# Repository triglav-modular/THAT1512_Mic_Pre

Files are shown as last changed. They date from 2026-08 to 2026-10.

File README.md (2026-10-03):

# µAmp
A THAT1512 microphone preamp. This is a very simple board with a THAT1512 based preamp for replacing the one in the Buchla 208 for a much lower noise floor and higher gain. Wire between the preamp jack and T.P.1 on card 10. Lower R6 on card 10 to compensate for the gain increase.

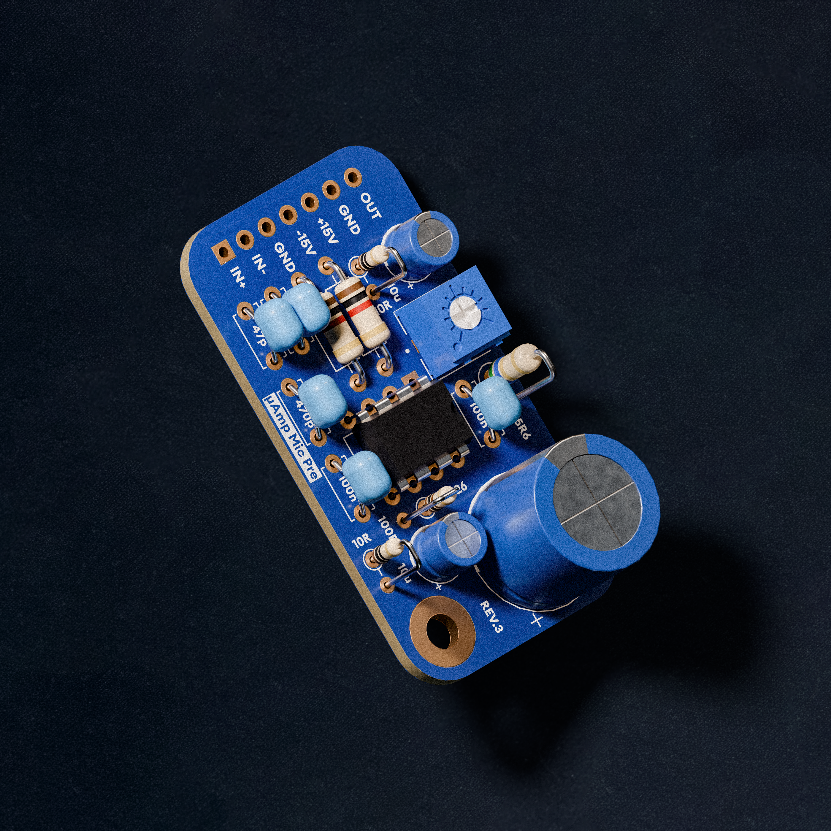
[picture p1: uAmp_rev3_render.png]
3D render of the assembled rev3 THAT1512 mic preamp board


The board is 45 × 24 mm with a single M3 mounting hole. Gain is set by the 1K trimmer (RV1, a Bourns 3362P): about 15 dB at full resistance up to about 59 dB at zero, where the 5.6 Ω R6 sets the top of the range.

## Header pinout

Pin 1 is the square pad.

| Pin | 1 | 2 | 3 | 4 | 5 | 6 | 7 |
|---|---|---|---|---|---|---|---|
| | i+ | i− | g | −v | +v | g | out |

## Revisions

**rev3 (2026)** — same outline, header pinout and mounting hole as rev2, so it is a drop-in replacement.

- Corrected part numbers: U1 is THAT1512P08-U (was 1510), C4/C5 are 100 nF (were 470 pF part numbers), R1/R2 are 1 kΩ (were 6.81 kΩ part numbers), RV1 is 1 kΩ.
- R3 100 Ω in series with the output, to isolate the THAT1512 from the capacitance of the wire to card 10 (it is specified for 300 pF at most).
- R6 5.6 Ω in series with RV1, so maximum gain is set by a resistor rather than by the trimmer's end resistance.
- R4/C7 and R5/C8: 10 Ω and 10 µF on each supply rail.
- No output coupling capacitor is needed: card 10 AC-couples after T.P.1, and C6 holds the output offset to a few mV.

**rev2 (2022)** — the board fitted in the 208, tagged `rev2`. Its raytraced render is `uAmp_3D_render.png`.

## Bill of materials (rev3)

| Ref | Value | Part number | Notes |
|---|---|---|---|
| U1 | THAT1512 | THAT1512P08-U | DIP-8 |
| RV1 | 1 kΩ trimmer | Bourns 3362P-1-102LF | |
| C1, C2 | 470 pF | Murata RDE5C2A471J0M1H03A | C0G, 5 mm pitch |
| C3 | 47 pF | Murata RDE5C2A470J0M1H03A | C0G, 5 mm pitch |
| C4, C5 | 100 nF | Murata RDER71H104K0M1H03A | X7R, 5 mm pitch |
| C6 | 6800 µF 6.3 V | Nichicon UVZ0J682MHD | 12.5 × 25 mm, 5 mm pitch. Polarized is correct here: both gain pins sit at the same DC level. Bipolar 6800 µF only comes as 18 × 35.5 mm, which does not fit |
| C7, C8 | 10 µF 50 V | Panasonic EEU-FR1H100 | 5 mm diameter, 2 mm pitch |
| R1, R2 | 1 kΩ 0.1 % | Vishay CMF551K0000BEEK | |
| R3 | 100 Ω | Vishay MBA02040C1000FC100 | mounted vertically |
| R4, R5 | 10 Ω | Vishay MBA02040C1009FC100 | mounted vertically |
| R6 | 5.6 Ω | Vishay MBB02070C5608FCT00 | mounted vertically |
| J1 | 1×7 pin header | | 2.54 mm |

## Substituting the SSM2019

THAT Corporation put the 1510 and 1512 on end-of-life status on 1 September 2026 ([memo](https://thatcorp.com/wp-content/uploads/2026/09/THAT-EOL-Memo.pdf)). The Analog Devices SSM2019BNZ (DIP-8) has the same pinout and fits U1 with no board change.

Its gain is 1 + 10 kΩ/Rg where the THAT1512's is 0.5 + 5 kΩ/Rg, so with the rev3 values the range moves up about 6 dB, to 21–65 dB. Two value changes bring it back to about 15.5–59 dB:

| Ref | With THAT1512 | With SSM2019 |
|---|---|---|
| R6 | 5.6 Ω | 11 Ω |
| RV1 | 1 kΩ (3362P-1-102LF) | 2 kΩ (3362P-1-202LF) |

Nothing else changes; C6 then rolls off near 2 Hz at full gain instead of 4 Hz.

By the datasheets the SSM2019 matches the THAT1512's 1 nV/√Hz input noise at 60 dB and is a little noisier below 40 dB (7 against 4.6 nV/√Hz at 20 dB). Its bandwidth at 60 dB is 200 kHz against 1.6 MHz, and its distortion there is about twice as high (0.017 % against 0.008 %, measured under different conditions). It drives 5000 pF where the THAT1512 is limited to 300 pF.

The TI INA217 shares the pinout and the SSM2019's gain equation, but TI no longer lists it in DIP-8.

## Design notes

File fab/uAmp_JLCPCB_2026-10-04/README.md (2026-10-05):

# µAmp rev 3 — JLCPCB bare-board package

Generated 2026-10-04 from `uAmp.kicad_pcb` as saved 2026-10-04 10:15:07
(sha256 `34b1dd3746bd…`), KiCad 10.0.6, `kicad-cli`. Bare boards only: no BOM,
no placement file.

Re-exported after the 09:58 package. The only change is that "TRIGLAV MODULAR"
moved on the back silkscreen. Apart from creation dates, only
`uAmp-B_Silkscreen.gbo` differs from the 09:58 files. KiCad also writes an empty
NPTH drill file and its map; both are left out because the board has no
unplated holes.

## Contents

| File | Purpose |
|---|---|
| `uAmp-gerbers.zip` | **upload this**: 9 gerbers, the job file and the drill file |
| `gerbers/` | the same files unzipped, plus the drill map PDF |

## Order parameters

| | |
|---|---|
| Dimensions | 45.00 × 24.03 mm, rounded corners |
| Layers | 2 |
| Thickness | 1.6 mm |
| Material | FR4 |
| Surface finish | HASL or ENIG, no constraint from this design |
| Min track / space | 0.50 / 0.25 mm |
| Vias | none |
| Copper to board edge | 0.20 mm or more |
| Holes | 47, all plated: 6 × 0.7, 3 × 0.714, 28 × 0.8, 7 × 1.0, 2 × 1.2, 1 × 3.2 mm (M3) |
| Order number | no marker on the board (the owner removed it 2026-10-04) |

## Verification performed

- DRC on the saved board: 0 errors, 0 unconnected, 11 warnings (10 library
  differences, 1 missing footprint library for RV1). One schematic-parity
  warning: U1's Value field.
- The saved zone fill equals a fresh fill (the owner refilled and saved;
  1210 mm² of GND pour over both layers).
- The project's copper-to-edge rule is 0.075 mm. DRC on a copy with the rule
  raised to 0.20 mm (JLCPCB's routed-edge minimum) and the zones refilled
  reports nothing.
- Read back from the files in this folder: the drill file's six tools and 47
  hits equal the board's pad holes; the outline is 45.000 × 24.030 mm; no
  coordinate on any layer lies outside it; the job file and the copper headers
  say 2 layers; the zip holds the same bytes as `gerbers/`.
- Silk gerbers are exported with the mask openings subtracted
  (`--subtract-soldermask`).
- Front and mirrored back plotted with the same options and looked at: the
  "µAmp Mic Pre" knockout plots with its µ; "TRIGLAV MODULAR" on the back reads
  the right way round.

## Not checked

- JLCPCB's own gerber preview. Look at it before paying.
- Silk text is 0.8 to 0.9 mm high; JLCPCB asks for 1.0 mm.

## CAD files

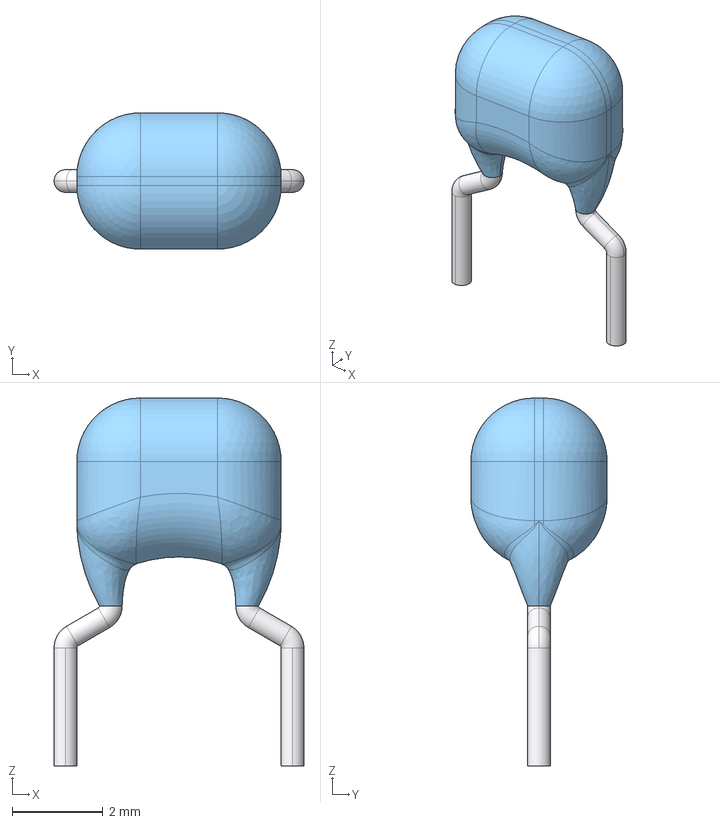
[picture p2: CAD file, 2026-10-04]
3dmodels/C_Ceramic_Dipped_P5.00mm.step
5.50 x 3.00 x 8.10 mm
leads

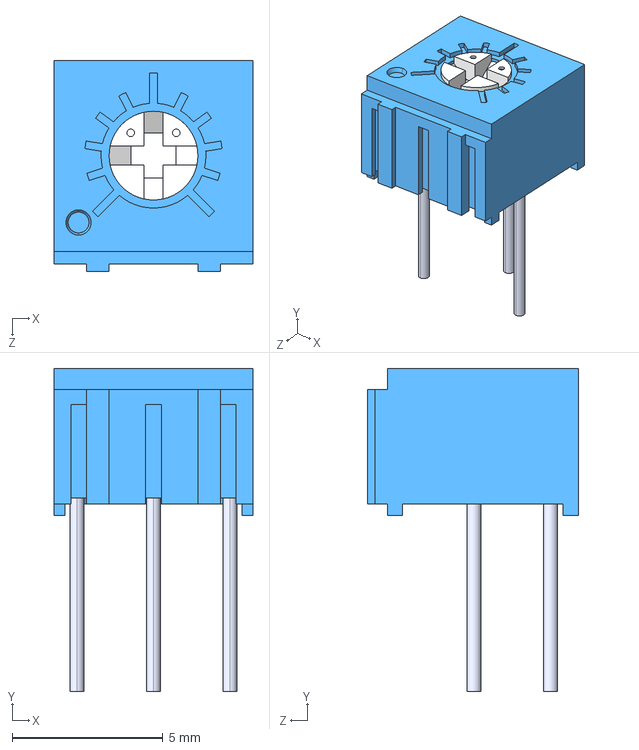
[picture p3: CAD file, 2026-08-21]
3dmodels/3362p-1-103.stp
6.60 x 10.7 x 6.99 mm

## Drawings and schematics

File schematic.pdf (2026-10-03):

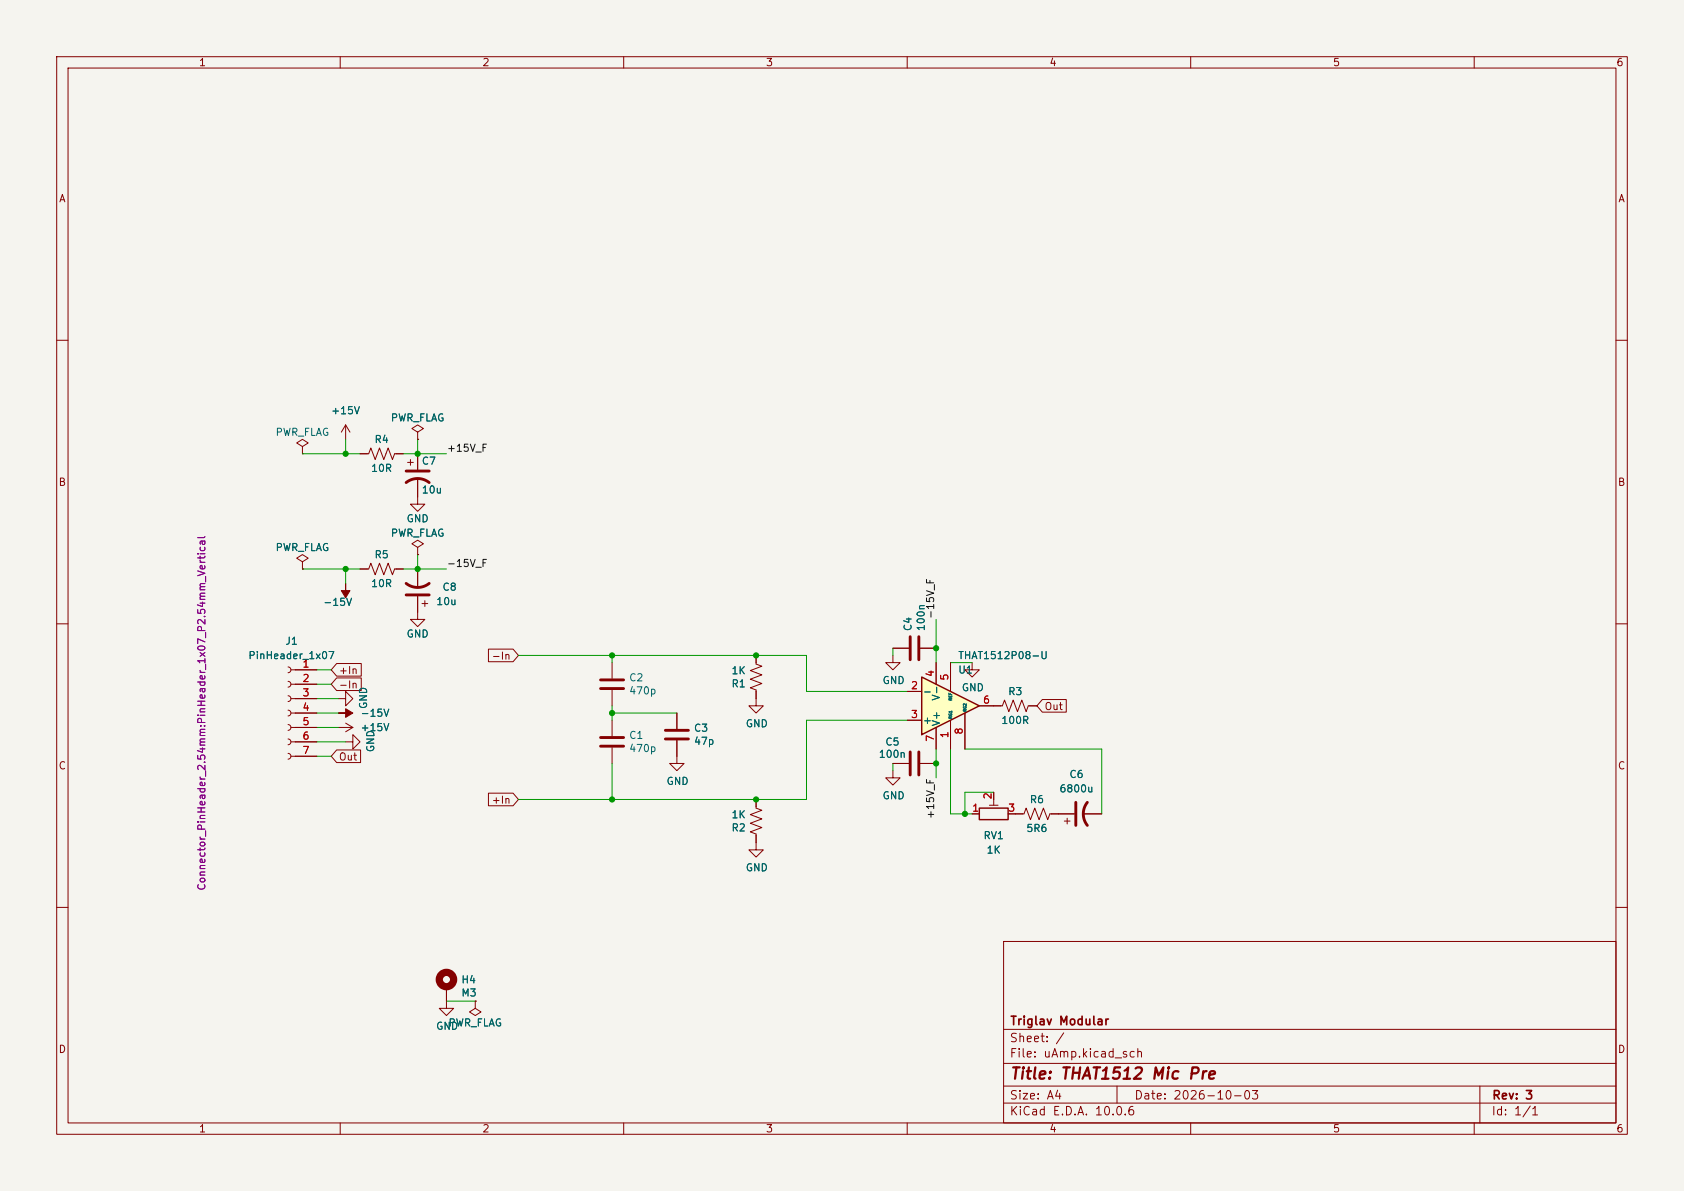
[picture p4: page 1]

Size: A4 | Rev: 3
KiCad E.D.A. 10.0.6 | Id: 1/1

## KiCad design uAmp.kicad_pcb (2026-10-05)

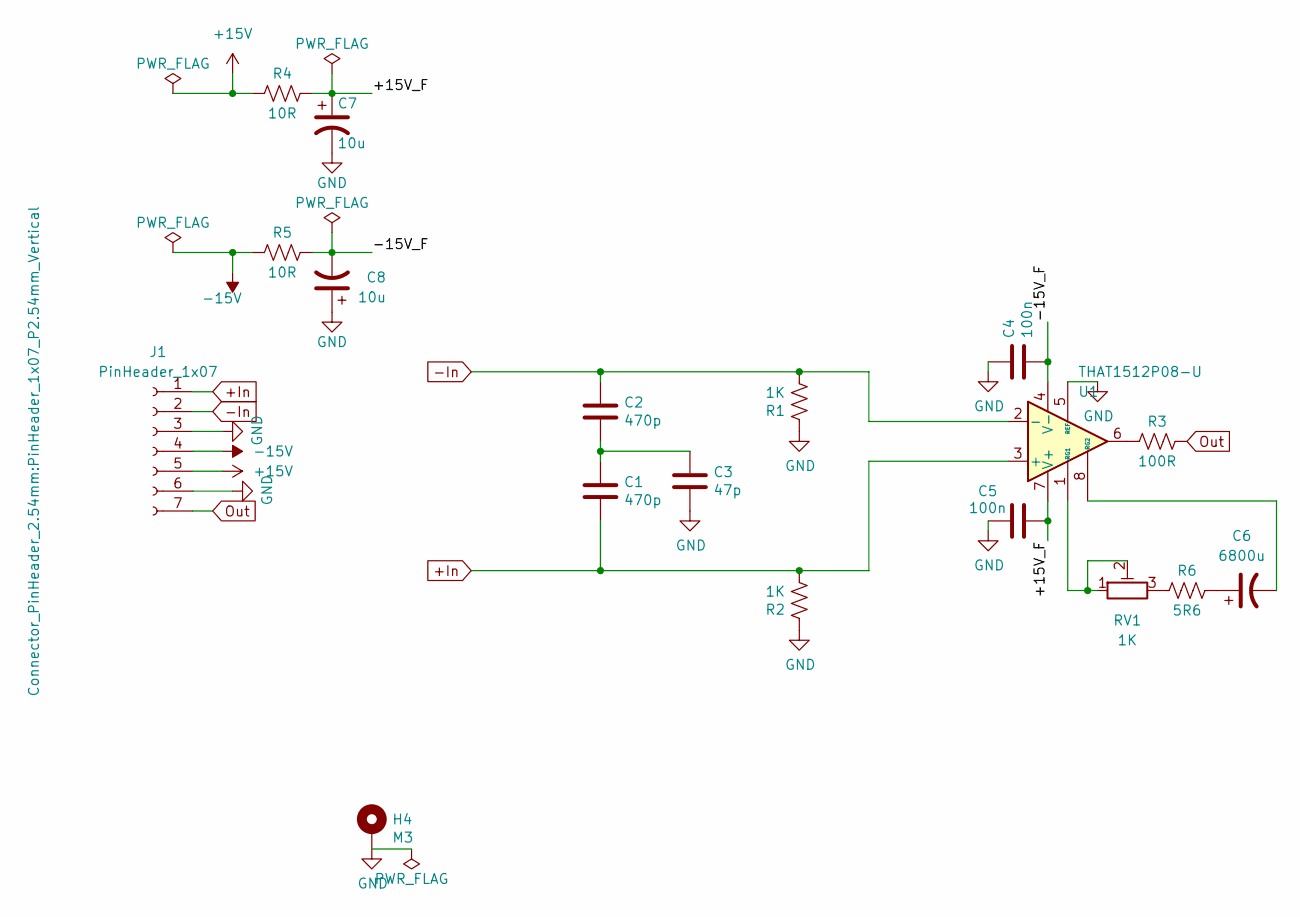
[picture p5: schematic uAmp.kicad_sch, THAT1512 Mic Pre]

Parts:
C1, C2: 470p; C_Disc_D5.0mm_W2.5mm_P5.00mm
C3: 47p; C_Disc_D5.0mm_W2.5mm_P5.00mm
C4, C5: 100n; C_Disc_D5.0mm_W2.5mm_P5.00mm
C6: 6800u; CP_Radial_D12.5mm_P5.00mm
C7, C8: 10u; CP_Radial_D5.0mm_P2.00mm
H4: M3; MountingHole_3.2mm_M3_Pad
J1: PinHeader_1x07; PinHeader_1x07_P2.54mm_Vertical
R1, R2: 1K; R_Axial_DIN0207_L6.3mm_D2.5mm_P10.16mm_Horizontal
R3: 100R; R_Axial_DIN0204_L3.6mm_D1.6mm_P2.54mm_Vertical
R4, R5: 10R; R_Axial_DIN0204_L3.6mm_D1.6mm_P2.54mm_Vertical
R6: 5R6; R_Axial_DIN0207_L6.3mm_D2.5mm_P2.54mm_Vertical
RV1: 1K; TRIM_3362P-1-103
U1: THAT1512P08-U; DIP-8_W7.62mm

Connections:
+15V: J1.5, R4.1
+In: C1.2, J1.1, R2.2, U1.3 (+)
-15V: J1.4, R5.1
-In: C2.1, J1.2, R1.2, U1.2 (-)
/+15V_F: C5.2, C7.1, R4.2, U1.7 (V+)
/-15V_F: C4.2, C8.2, R5.2, U1.4 (V-)
GND: C3.2, C4.1, C5.1, C7.2, C8.1, H4.1, J1.3, J1.6, R1.1, R2.1, U1.5 (REF)
unnamed: C1.1, C2.2, C3.1
unnamed: C6.1, R6.2
unnamed: R3.1, U1.6
unnamed: R6.1, RV1.3
unnamed: RV1.1, RV1.2, U1.1 (RG1)
unnamed: C6.2, U1.8 (RG2)
Out: J1.7, R3.2

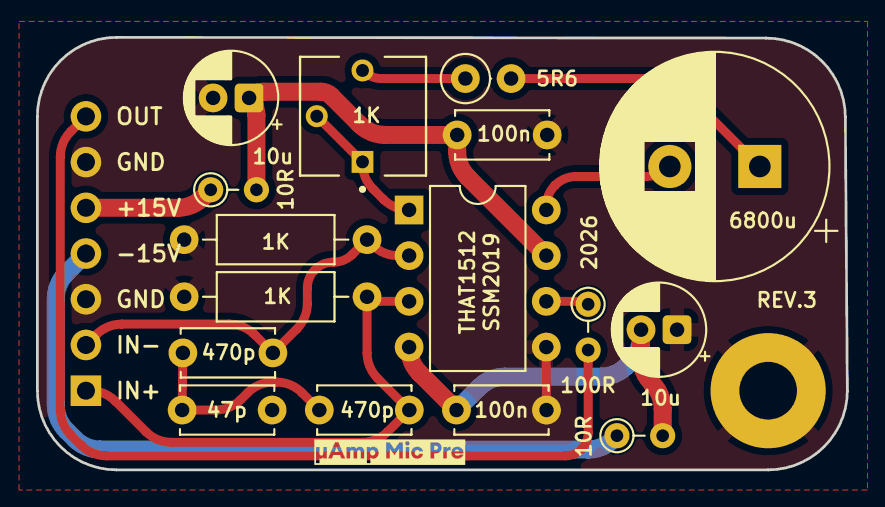
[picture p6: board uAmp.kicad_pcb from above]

Board: 2 copper layers, 45.0 x 24.0 mm, 18 parts (0 on the bottom side), 14 nets.

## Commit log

2022-04-22 add 3d render
    [thatmicpre.kicad_pcb]
2022-04-23 change C6 footprint
    [thatmicpre.kicad_pcb]
2022-05-15 rounded tracks
    [thatmicpre-rounded.kicad_pcb]
2026-08-21 Updated models and render
    [3362p-1-103.stp, thatmicpre.blend]
2026-10-02 Migrate schematic and board to KiCad 10 format; drop the KiCad 5 .pro
    kicad-cli sch/pcb upgrade only. Exported netlist identical before and
    after; DRC violations identical. thatmicpre-rounded.kicad_pcb is left as
    rev2's derived fab file and is regenerated once rev3 is laid out.
    [thatmicpre.kicad_pcb, thatmicpre.kicad_sch]
2026-10-03 rev3 schematic: correct part numbers, output and rail resistors, gain stop
    Part-number (Vendor) fields that named the wrong part:
    - U1 THAT1510P08-U -> THAT1512P08-U (the 1510 has a different gain law)
    - C4, C5 (100n) carried the 470 pF RDE5C2A471...; now RDER71H104K0M1H03A
    - R1, R2 (1k) carried a 6.81 k CMF556K8100BEEK; now CMF551K0000BEEK
    - RV1 value 5K -> 1K, matching the board and README; 3362P-1-102LF
    - C6 had no footprint in the schematic; now CP_Radial_D12.5mm_P5.00mm
    Added:
    - R3 100R build-out between U1 pin 6 and Out (cable capacitance;
    THAT1512 is specified to 300 pF)
    - R6 5R6 in series with RV1 and C6: defines the top of the gain range
    (~59 dB with RV1 at zero) instead of lea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
    [thatmicpre-rounded.kicad_pcb, thatmicpre.kicad_sch]
2026-10-03 rev3 board: place and route R3-R6, C7, C8; sync nets and part data
    Same outline, J1 position and pinout, and M3 hole: a drop-in for rev2.
    - R4/C7 (+15V filter) in the free pocket beside J1; R6 (gain stop) on the
    RV1-C6 track along the top edge; R3 (output build-out), R5/C8 (-15V
    filter) between U1, C6 and H4. Out now leaves U1 through R3.
    - -15V_F returns to C4/U1 pin 4 on a short B.Cu run; C4's ground gets a
    direct F.Cu track to U1 pin 5, and C4 pad 1 / J1 pad 3 connect solid to
    the pour (both were starved thermals; J1's dates from rev2).
    - Nets, values and Vendor fields synced to the rev3 schematic; footprint
    paths point at the schematic symbols. Removed a stray 1.3 mm cross on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
    [thatmicpre.kicad_pcb]
2026-10-03 rev3: rounded tracks, README, schematic PDF, render
    - Tracks filleted in the board itself (40 corners, radius up to 2 mm) with
    the tooling lane's fillet_adaptive.py run headless, instead of rev2's
    separate -rounded copy; unfillet() in that script restores the corners.
    DRC with schematic parity unchanged: 0 errors, 0 unconnected, 0 parity.
    - README: rev3 changes, gain range, BOM with the corrected part numbers.
    C6's part number is left blank: the fitted part is not recorded.
    - schematic.pdf regenerated from the rev3 schematic; kicad-cli render.
    [thatmicpre.kicad_pcb]
2026-10-03 Rename to uAmp; rev3 layout rework, C6 part number, rev2-style render
    - Project renamed thatmicpre -> uAmp (files, README title, backups ignore).
    - Layout (owner): U1, RV1, C5-C8, R1, R2, R4, R6 moved; GND pour now on
    both layers; header silk relabelled OUT/GND/+15V/-15V/GND/IN-/IN+;
    "uAmp" and "REV.3" added.
    - Tidy after the moves: unfillet, collapse drag stubs, redraw seven
    jogged runs (U1 pins 2/3/4/6/7, R4-C7, C6 pad 1) as clean 45-degree
    paths, delete an accidental B.Cu duplicate of the +15V J1-R4 run, J1
    pad 6 solid to the pour, then re-fillet (one corner by RV1 at 0.8 mm
    to keep clearance). Placement, silk and pour untouched by the tidy.
    DRC with schematic parity: 0 erro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
    [uAmp.kicad_pcb, uAmp.kicad_sch]
2026-10-04 rev3 board as saved 2026-10-04; JLCPCB bare-board package
    Board: silk rework (µAmp Mic Pre knockout with a composed µ, SSM2019, 2026,
    TRIGLAV MODULAR on the back), the JLCJLCJLCJLC marker removed, zones refilled,
    dipped-ceramic 3D models for C1-C5 in 3dmodels/. Render redone.
    fab/uAmp_JLCPCB_2026-10-04: gerbers and drill from this save (sha256
    7fce3061e375), no BOM or placement file. DRC 0 errors, 0 unconnected.
    [C_Ceramic_Dipped_P5.00mm.step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]
2026-10-05 rev3 board as saved 10:15 and its re-exported JLCPCB package (owner)
    Back-silkscreen TRIGLAV MODULAR moved; the package README records the
    re-export. Committed as the final rev3 state before the rev4 layout
    rewrites uAmp.kicad_pcb. Rev3 was never ordered.
    [uAmp-B_Cu.gbl, uAmp-B_Mask.gbs, uAmp-B_Paste.gbp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]
